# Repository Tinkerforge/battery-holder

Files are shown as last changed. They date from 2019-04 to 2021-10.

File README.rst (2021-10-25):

Battery Holder
==============

**This Bricklet is currently in development.**

This repository contains the hardware design
files. The documentation generator configs can be found at
https://github.com/Tinkerforge/generators

Repository Content
------------------

hardware/:
 * Contains KiCad project files and additionally schematics as PDF

datasheets/:
 * Contains datasheets for sensors and complex ICs that are used

Hardware
--------

The hardware is designed with the open source EDA Suite KiCad
(http://www.kicad.org). Before you are able to open the files,
you have to install the Tinkerforge kicad-libraries
(https://github.com/Tinkerforge/kicad-libraries). You can either clone
them directly in hardware/ or clone them in a separate folder and
symlink them into hardware/
(ln -s kicad_path/kicad-libraries project_path/hardware). After that you
can open the .pro file in hardware/ with KiCad and from there view and
modify the schematics and the PCB layout.

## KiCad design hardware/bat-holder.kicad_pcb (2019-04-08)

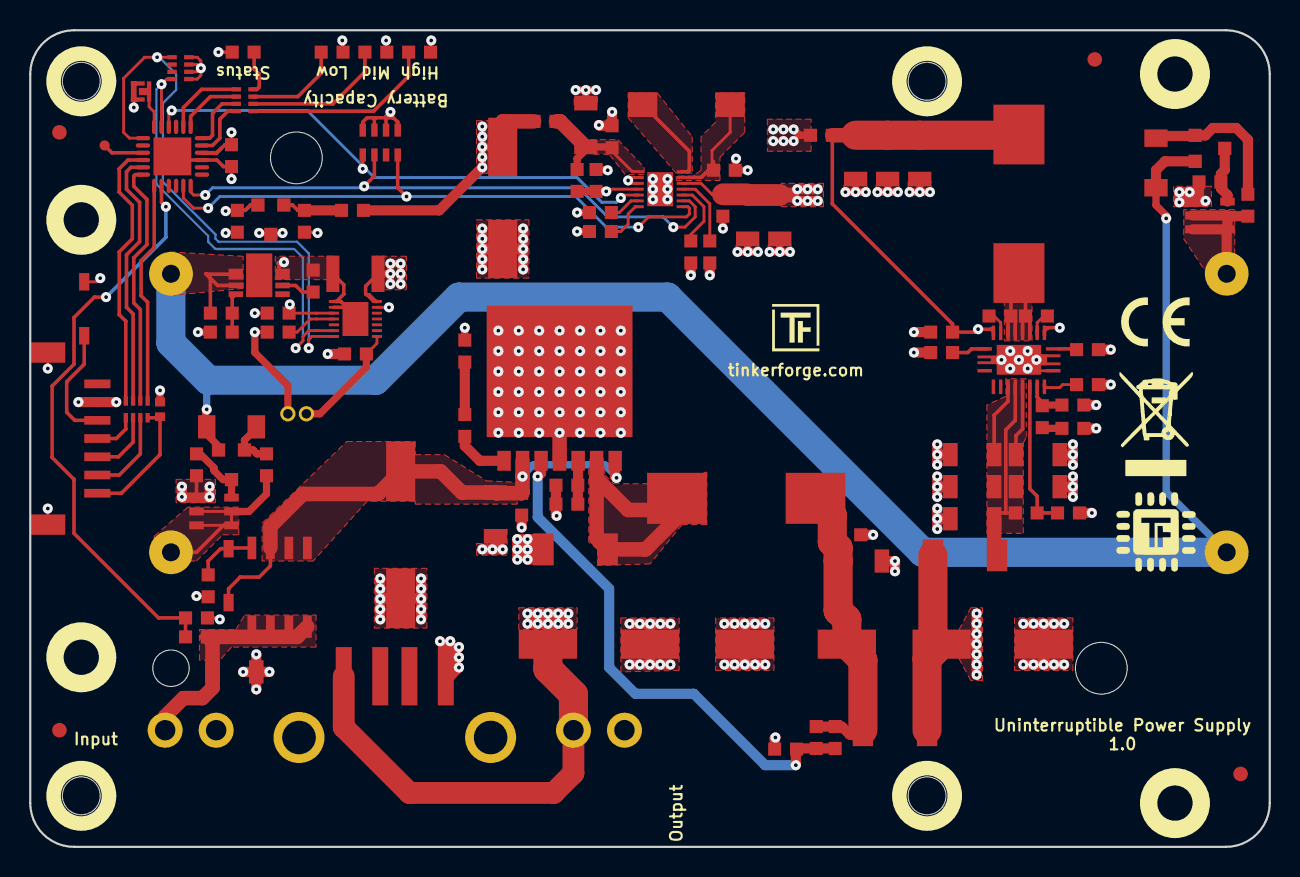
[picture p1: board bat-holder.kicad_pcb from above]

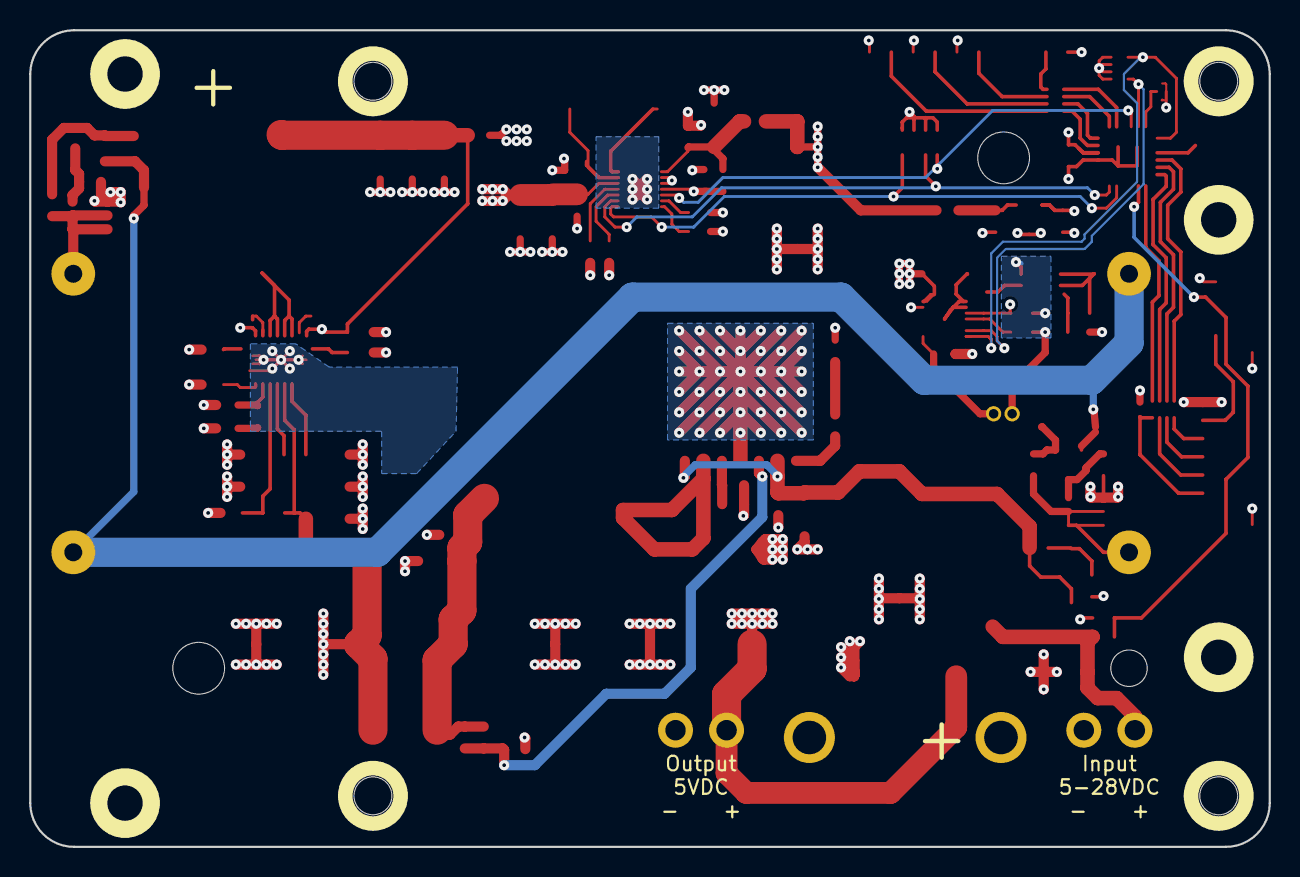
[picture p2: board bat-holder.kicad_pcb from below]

Board: 4 copper layers, 85.0 x 56.0 mm, 121 parts (2 on the bottom side), 70 nets.

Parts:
C101, C102, C209, C220, C228, C230: 100nF; C0603F
C103: 220pF; C0402F
C104, C204, C207, C222, C224: 100nF/16V; C0603F
C105: 470nF; C0603F
C106, C225, C229, C233: 470µF/16V; ELKO_83
C107, C108, C226: 1uF; C0603F
C201, C202, C203, C208, C214, C215, C216, C217, C218, C221, C223, C231, C232: 10uF; C1206
C205: 2.2uF; C0603F
C206: UWT1H221MNL1GS; ELKO_103
C210: 8.2nF; C0603F
C211: 100pF; C0603F
C212: 36pF; C0603F
C213: 680pF; C0603F
C219: 4.7nF; C0603F
C227: DNP; C0603F
D101, D102: LL4148; MiniMelf
D103: blue; D0603F
D104, D105, D106: green; D0603F
D107: B0520LW-7; SOD-123
D201: Z12V; SOD-123
D202, D203, D204: PMEG6045; SOD-128
Fiducial_Mark: VAL**; Fiducial_Mark
Fiducial_Mark#2, Fiducial_Mark#3, Fiducial_Mark#4: VAL**; Fiducial_Mark
J101: BAT_1049P
J102: USB-A; USB-A-SMT-8231
K101: NTC; Pin_Header_Straight_1x02_127
L201: 1uH 74437368010; WE-LHMI
L202: 22uH 74437368220; WE-LHMI
L203: 4.7uH 7447789004; WE-PD
P101: BOOT; SolderJumper
P102: DEBUG; DEBUG_PAD
P103: CON-SENSOR2
P105: 5V Out; OQ_2P
P201: Input; OQ_2P
Q101, Q102: BC846; SOT23EBC
Q103, Q104: DMP2035UVTQ; SOT26GDS
Q201: Si4447ADY; SOIC-8-MOSFET
R1, R2, R3: 0; R0603F
R101, R102, R103, R104, R202, R204, R221: 10k; R0603F
R107: 330; R0603F
R108: 2.7k; R0603F
R109: DNP; R0603F
R110: 10m; R1210
R201: VC120626D580DP; R1206
R203: 1k; R0603F
R205: 332k; R0603F
R206: 105k TBD; R0603F
R207: 27; R0603F
R208: 36.5k; R0603F
R209: 309k; R0603F
R210: 86.6k; R0603F
R211: 20k; R0603F
R212: 100; R0603F
R213: 47k; R0603F
R214: 8.2k; R0603F
R217: 49.9k; R0603F
R219: 100k; R0603F
RP101: 1k; 4X0402
RP102: 82; 4X0402
RP103: 10k; 4X0402
RP201: 1k; 4X0603
U101: XMC1XXX24; QFN24-4x4mm-0.5mm
U102: AP9211; DFN2030-6
U103: MAX17260_LS; TDFN14-3x3
U104, U105, U106, U107: DRILL; DRILL_NP
U108, U109, U110, U111: DRILL; DRILL_26
U112: AP7333-33SA; SOT23-3
U201: TPS61088RHL; VQFN20_45x35
U202: BD906XX-C-HRP7
U203: AAT3620; TDFN14-3x3
VAL: CE_5mm
VAL#2: WEEE_7mm

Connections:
3V3: C101.1, C108.2, D103.1, D104.1, D105.1, D106.1, D107.2, RP103.5, RP103.6, RP103.7, RP103.8, RP201.1, RP201.2, RP201.3, RP201.4, U101.10, U112.2
5VOUT: C214.1, C215.1, C216.1, C217.1, C218.1, D202.1, R209.1, U201.14, U201.15, U201.16
+5V: C106.1, C229.1, C233.1, D202.2, D204.2, J102.1, P105.1, R1.2, R3.2
AGND: C104.2, C105.1, K101.2, R108.1, R110.1, U102.6, U103.8, U103.9, U103.EP
BATTERY-SCL: RP103.1, U101.19, U103.14
BATTERY-SDA: RP103.4, U101.17, U103.13
BAT_OUT: C104.1, C230.1, C231.1, C232.1, Q103.S, Q104.S, R2.1, R103.2, R104.2, R107.2, R109.2, U103.6, U103.10, U203.12
CHARGER_EN: RP201.8, U101.16, U203.5
CHARGER_STAT1: RP201.7, U101.6, U203.9
CHARGER_STAT2: RP201.5, U101.5, U203.8
CHG_IN: C207.2, L201.2, R205.2, U201.4, U201.5, U201.6, U201.7
DC-IN-VOLTAGE: R202.2, R203.1, U101.2
GBAT: C102.2, D101.1, D102.1, J101.2, J101.4, Q101.E, Q102.E, U102.1, U102.2
GND: C101.2, C103.2, C106.2, C107.1, C108.1, C201.2, C202.2, C203.2, C204.2, C205.2, C206.2, C208.2, C209.2, C210.2, C211.2, C212.2, C213.2, C214.2, C215.2, C216.2, C217.2, C218.2, C219.2, C220.2, C221.2, C222.2, C223.2, C224.2, C225.2, C226.2, C228.2, C229.2, C230.2, C231.2, C232.2, C233.2, D203.1, J102.4, J102.SHD, P101.1, P103.2, P103.EP, P105.2, P201.2, R110.2, R201.2, R203.2, R204.2, R206.2, R207.1, R210.2, R214.1, R217.2, R219.2, U101.9, U101.EXP, U103.7, U112.3, U201.20, U201.EXP, U202.4, U202.EXP, U203.2, U203.3, U203.EP
L1: L203.2, U203.14
L2: C228.1, L203.1, U203.13
unnamed: C102.1, R107.1, U102.3
unnamed: C103.1, P103.7, RP102.4
unnamed: C105.2, U103.11
unnamed: C107.2, R1.1, U112.1
unnamed: C201.1, C202.1, C203.1, C204.1, L201.1, R2.2, U201.2, U201.9
unnamed: C205.1, U201.1
unnamed: C207.1, U201.8
unnamed: C210.1, U201.10
unnamed: C211.1, R207.2, U202.5
unnamed: C212.1, R208.1, U201.18
unnamed: C213.1, R208.2
unnamed: C219.1, R211.1
unnamed: C220.1, C223.1, C225.1, C227.1, D204.1, L202.2, R213.2
unnamed: C221.1, C222.1, R3.1, R212.1, U203.1
unnamed: C224.1, U203.7
unnamed: C227.2, R213.1, R214.2, U202.3
unnamed: D101.2, Q101.B, R101.1
unnamed: D102.2, Q102.B, R102.1
unnamed: D103.2, RP101.8
unnamed: D104.2, RP101.7
unnamed: D105.2, RP101.6
unnamed: D106.2, RP101.5
unnamed: D107.1, P103.3
unnamed: D201.1, Q201.G, R204.1
unnamed: K101.1, R109.1, U103.1
unnamed: P101.2, U101.18
unnamed: P102.1, U101.21
unnamed: P103.4, RP102.1
unnamed: P103.5, RP102.2
unnamed: P103.6, RP102.3
unnamed: Q101.C, Q103.G, R103.1
unnamed: Q102.C, Q104.G, R104.1
unnamed: R108.2, U102.5
unnamed: R205.1, U201.3
unnamed: R206.1, U201.19
unnamed: R209.2, R210.1, U201.17
unnamed: R211.2, U202.1
unnamed: R217.1, U203.10
unnamed: R219.1, U203.6
unnamed: R221.2, U203.11
unnamed: RP101.1, U101.14
unnamed: RP101.2, U101.13
unnamed: RP101.3, U101.12
unnamed: RP101.4, U101.11
SPI-CLK: RP102.7, U101.23
SPI-CS: RP102.8, U101.22
SPI-MISO: RP102.5, U101.1
SPI-MOSI: RP102.6, U101.24
VBAT1: J101.1, Q103.D, R101.2
VBAT2: J101.3, Q104.D, R102.2
VCC: C226.1, R212.2, R221.1, U203.4
VIN: P201.1, Q201.D, R201.1, R202.1
VIN2: C206.1, C208.1, C209.1, D201.2, Q201.S, U202.2, U202.7
VSW: D203.2, L202.1, U202.6

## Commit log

2018-10-24 prototype hardware checkin
    [bat-holder.kicad_pcb, bat-holder.sch]
2018-11-14 change to ap9211 battery protection ic
    [bat-holder.kicad_pcb, bat-holder.sch]
2018-11-14 add battery hint
    [bat-holder.sch]
2018-11-20 add hint, add datasheet
    [bat-holder.kicad_pcb, bat-holder.sch]
2018-11-23 change reverse polarity protection of batteries
    [bat-holder.kicad_pcb, bat-holder.sch]
2018-11-23 change ntc routing
    [bat-holder.kicad_pcb]
2018-11-23 add debugging resistors
    [bat-holder.kicad_pcb, bat-holder.sch]
2018-12-06 fix bc846 footprints, fix connector orientation
    [bat-holder.kicad_pcb, bat-holder.sch]
2019-03-01 routing nearly completed
    [bat-holder.kicad_pcb, bat-holder.sch]
2019-03-04 fully routed
    [bat-holder.kicad_pcb, power_supply.sch, test.sch]
2019-03-04 prototype finished
    [bat-holder.kicad_pcb]
2019-03-25 fix diode footprint
    [bat-holder.kicad_pcb, bat-holder.sch]
2019-03-29 changed slikscreentext on bottomlayer <Output 5VDC>
    [bat-holder.kicad_pcb]
2019-04-08 added 0 ohm resistors and extented footprints for prototyping
    [bat-holder.kicad_pcb, bat-holder.sch, power_supply.sch]
2021-10-25 Update KiCad link
    https://www.kicad.org/blog/2021/10/Avoid-links-to-former-kicad-domain/

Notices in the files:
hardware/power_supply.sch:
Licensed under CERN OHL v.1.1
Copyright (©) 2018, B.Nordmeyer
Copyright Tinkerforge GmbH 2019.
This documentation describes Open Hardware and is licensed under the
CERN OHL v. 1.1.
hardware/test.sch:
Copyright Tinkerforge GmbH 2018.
